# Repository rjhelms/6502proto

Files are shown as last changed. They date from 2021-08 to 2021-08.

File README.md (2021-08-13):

# 6502 Protoboard

A prototyping board for experimenting with 6502 hardware and software design



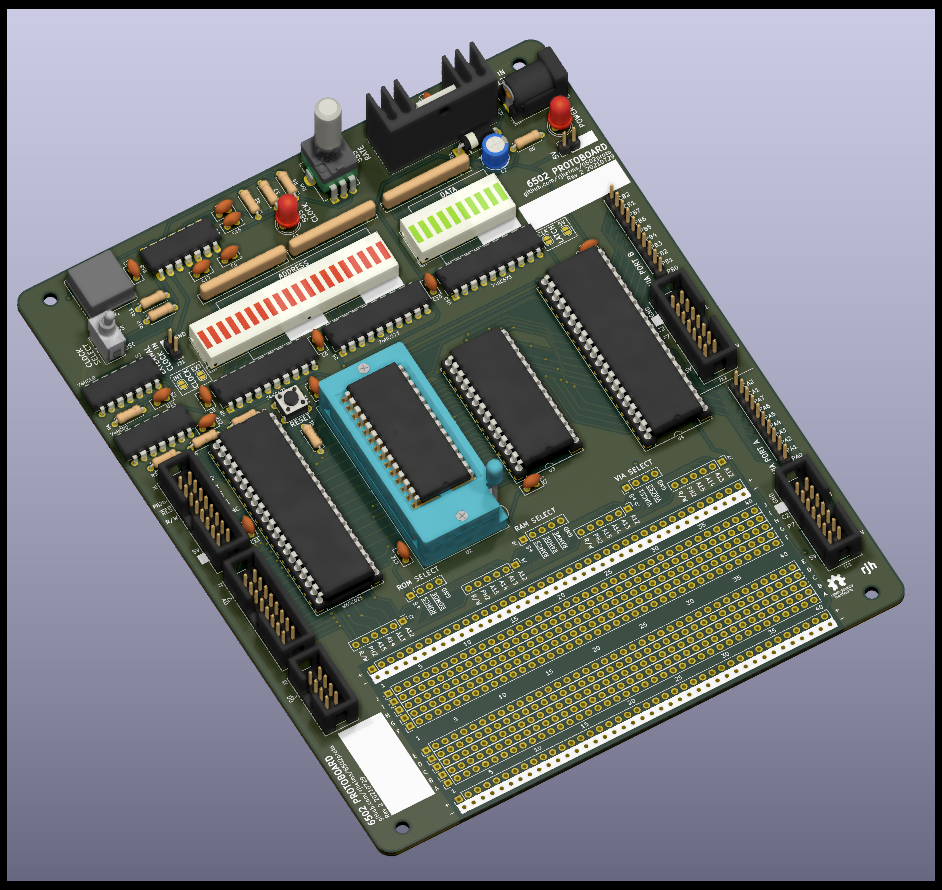
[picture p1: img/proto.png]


This board implements a minimal 6502 system, containing a 65C02 processor, a 65C22 Versatile Interface Adapter (VIA), a 32kB EEPROM and 32kB of SRAM.

This project would not have been possible without Garth Wilson's excellent [6502 Primer](https://wilsonminesco.com/6502primer/index.html), which is eseential reading for anyone looking to get started with 6502 homebrew.

## Table of contents

- [Features](#features)
- [Building](#building)
- [Implementing address decoding](#implementing-address-decoding)
  - [Minimal setup](#minimal-setup)
  - [Adding more I/O](#adding-more-i-o)
- [Header pinouts](#header-pinouts)
  - [CPU signals](#cpu-signals)
  - [Address bus](#address-bus)
  - [CPU bus](#cpu-bus)
  - [VIA ports](#via-ports)
- [Useful links](#useful-links)

## Features

- Two clock sources: 1MHz crystal oscillator "fast" clock and 555-timer based "slow" clock (approx 0.5Hz - 500Hz)
- Blinkenlights for the address and data buses
- Header for external clock source, if desired
- 400-point breadboard area, for address decoding and other small circuits
- IDC headers for address & data buses, CPU signals, and both VIA ports

## Building

More to come - for now, refer to the [interactive BOM](https://rjhelms.github.io/6502proto/ibom.html).

## Implementing address decoding

In order to let the 6502 processor talk to other chips, any 6502 system requires some address decoding logic. The board has no address decoding built in; it is up to the builder to implement their chosen address decoding with the breadboard area.

Pads above the breadboard area provide access to the 4 highest bytes of the address bus, as well as the PH2 clock and R/W, and the relevant inputs for each of the on-board ICs.

The [address decoding chapter](https://wilsonminesco.com/6502primer/addr_decoding.html) of Garth Wilson's primer is well worth a read before deciding what to implement.

Some key considerations when choosing an address decoding scheme:

- Each address should select at most one device
- Writes to RAM should only occur when PH2 is high
- RAM should be at the bottom of the address space, to include the  zero  page ($0000-$00FF) and stack ($0100-$01FF).
- ROM should be at the top of the address space, to include the reset and interrupt vectors at $FFFA-$FFFF.

### Minimal setup

For a system only using the RAM, ROM, and VIA chips on board, satisfactory results can be achieved with a single 74HC00 quad NAND gate:

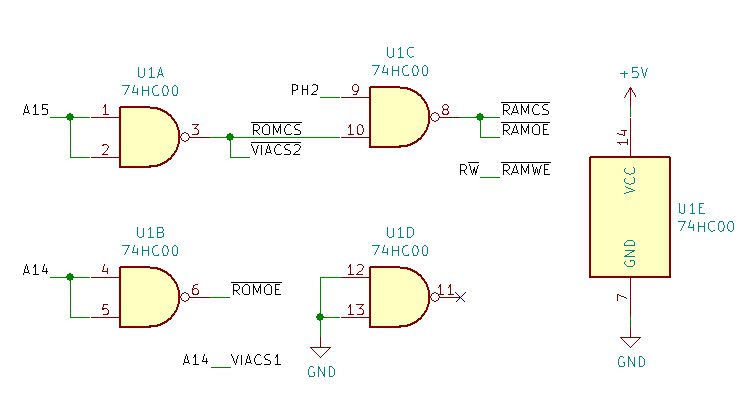
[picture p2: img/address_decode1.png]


| Start | End | Device |
|---|---|---|
| $0000 | $7FFF | RAM |
| $8000 | $BFFF | VIA |
| $C000 | $FFFF | ROM |

With only 64kB of address space and 32kB of both RAM and ROM, at least some portion of one of these will need to be masked by the VIA or other devices. This logic masks the lower half of ROM, resulting in a system with 32kB of RAM and 16kB of ROM.

A similar addressing scheme with 16kB of RAM and 32kB of ROM can also be implemented with one 74HC00.

### Adding more I/O

The minimal setup above works just fine for the chips on the protoboard, but doesn't leave any room for expanding the system any further. Also, while the VIA only needs 16 bytes of address space, the above setup allocates a whole 16kB to it!

By using a 74HC138 line decoder, that 16kB can be split into 8 2kB segments, each addressed by one output.

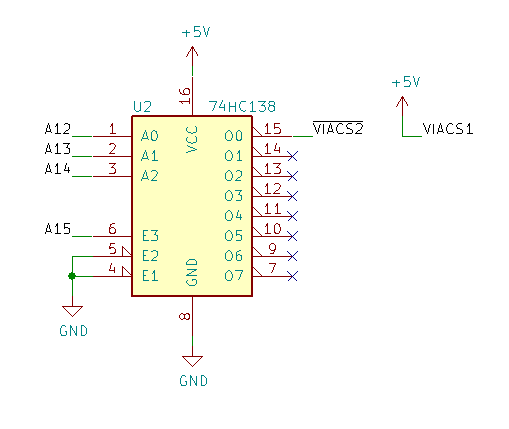
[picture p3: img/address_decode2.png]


| Start | End | Device |
|---|---|---|
| $0000 | $7FFF | RAM |
| $8000 | $87FF | (VIA) '138 output 0 |
...
| $B800 | $BFFF | '138 output 7 |
| $C000 | $FFFF | ROM    |

## Header pinouts

### CPU signals

| Pin | Signal | Pin | Signal |
|-----|---|-----|---|
| 1 | PH2 | 2 | PH2 |
| 3 | RESET  | 4 | RDY |
| 5 | R/W | 6 | IRQ |
| 7 | unused | 8 | NMI |
| 9 | unused | 10  | SYNC |
| 11  | unused | 12  | BE |
| 13  | 5V | 14  | 5V |
| 15  | GND | 16  | GND |

### Address bus

| Pin | Signal | Pin | Signal |
|-----|---|-----|---|
| 1 | A0 | 2 | A1 |
| 3 | A2 | 4 | A3 |
| 5 | A4 | 6 | A5 |
| 7 | A6 | 8 | A7 |
| 9 | A8 | 10  | A9 |
| 11  | A10 | 12  | A11 |
| 13  | A12 | 14  | A13 |
| 15  | A14 | 16  | A15 |

### CPU bus

| Pin | Signal | Pin | Signal |
|-----|---|-----|---|
| 1 | D0 | 2 | D1 |
| 3 | D2 | 4 | D3 |
| 5 | D4 | 6 | D5 |
| 7 | D6 | 8 | D7 |

### VIA ports

| Pin | Signal | Pin | Signal |
|-----|---|-----|---|
| 1 | 5V | 2 | 5V |
| 3 | PA0 | 4 | PA1 |
| 5 | PA2 | 6 | PA3 |
| 7 | PA4 | 8 | PA5 |
| 9 | PA6 | 10  | PA7 |
| 11  | CA1 | 12  | CA2 |
| 13  | GND | 14  | GND |

## Useful links

- [6502.org](http://6502.org/) - a wealth of information on 6502 hardware and software
- Garth Wilson's [6502 Primer](https://wilsonminesco.com/6502primer/index.html)
- Western Design Center, with datasheets and other useful info
  - [W65C02S 8-bit Microprocessor](https://www.westerndesigncenter.com/wdc/w65c02s-chip.php)
  - [W65C22 Versatile Interface Adapter (VIA)](https://www.westerndesigncenter.com/wdc/w65c22-chip.php)
- [cc65](https://cc65.github.io/), a 6502 C compiler and assembler

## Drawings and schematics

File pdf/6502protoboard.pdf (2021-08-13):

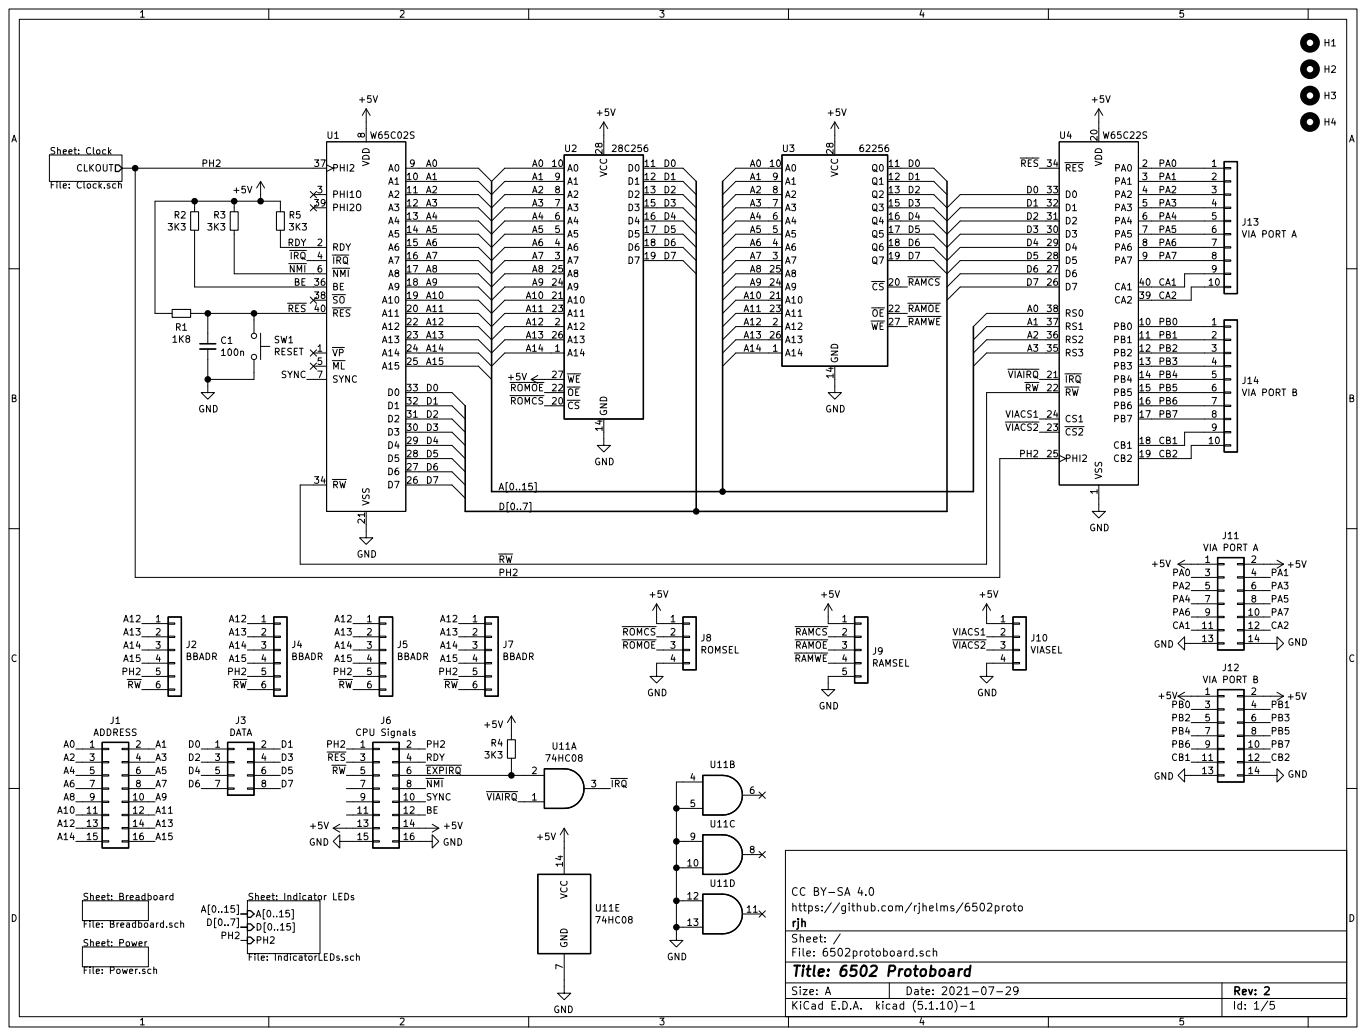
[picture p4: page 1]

Sheet: Clock File: Clock.sch CLKOUT

https://github.com/rjhelms/6502proto CC BY-SA 4.0

File: 6502protoboard.sch Sheet: / rjh

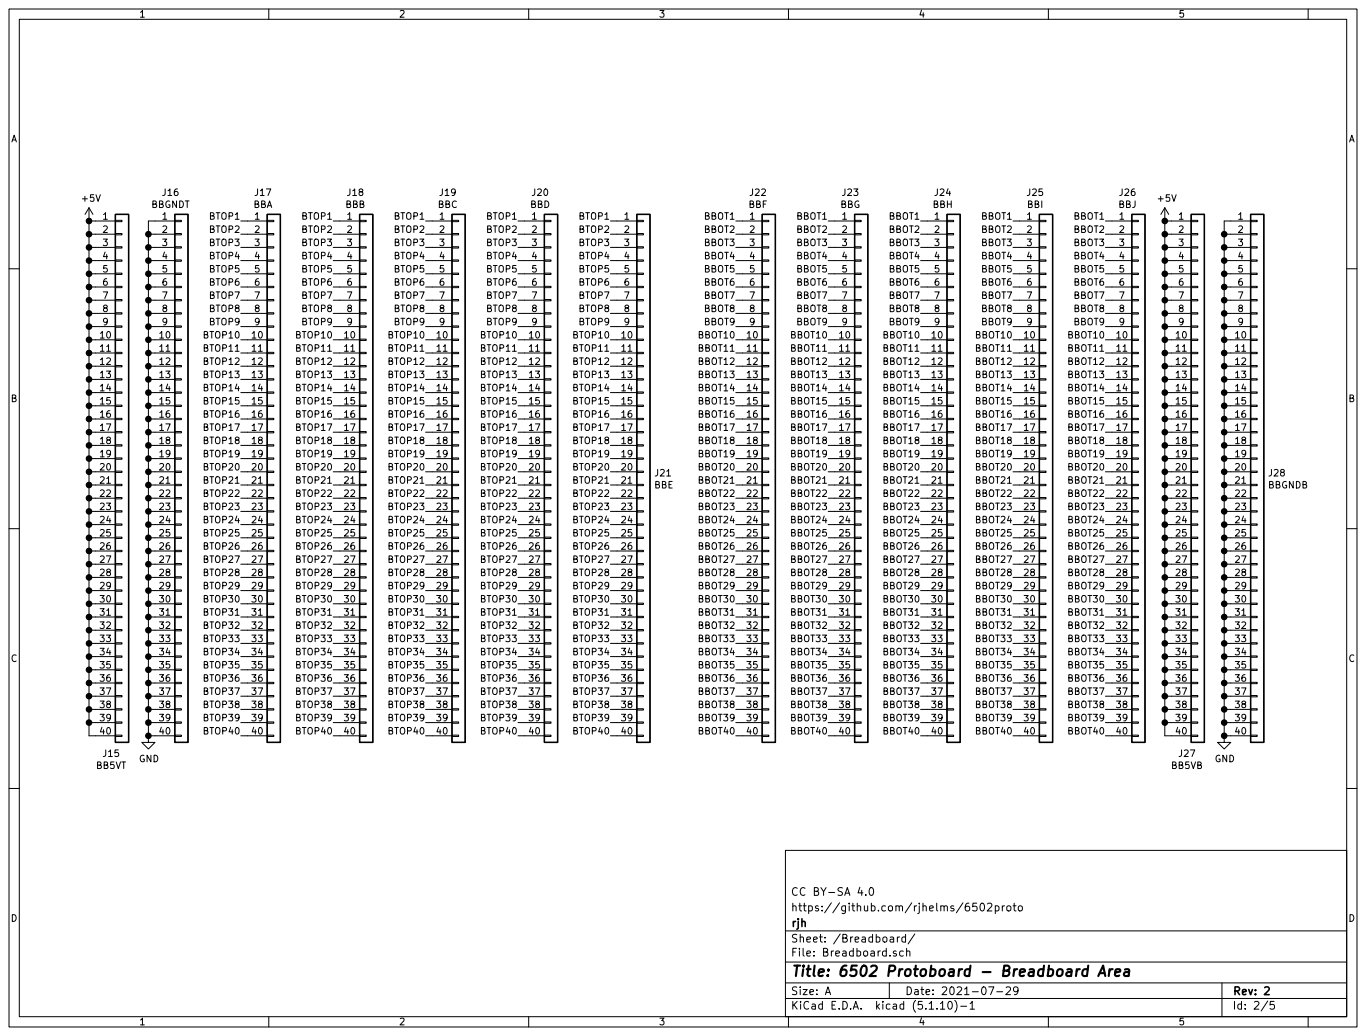
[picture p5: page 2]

https://github.com/rjhelms/6502proto CC BY-SA 4.0

File: Breadboard.sch Sheet: /Breadboard/ rjh

Id: 2/5 Title: 6502 Protoboard - Breadboard Area

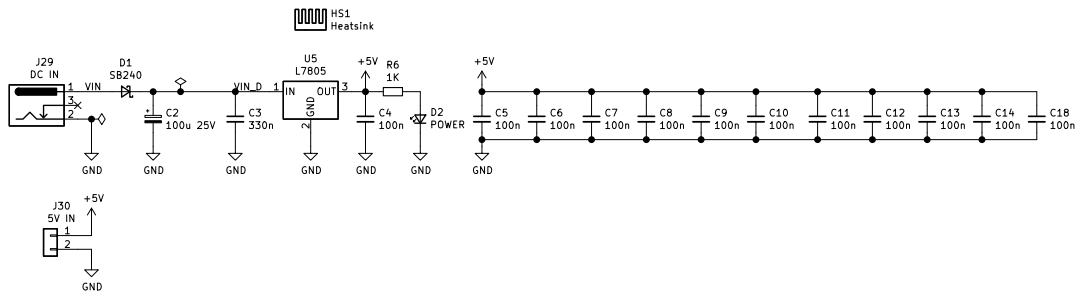
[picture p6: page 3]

https://github.com/rjhelms/6502proto CC BY-SA 4.0 D2 POWER
100n GND

Id: 3/5 Title: 6502 Protoboard - Power File: Power.sch Sheet: /Power/ rjh

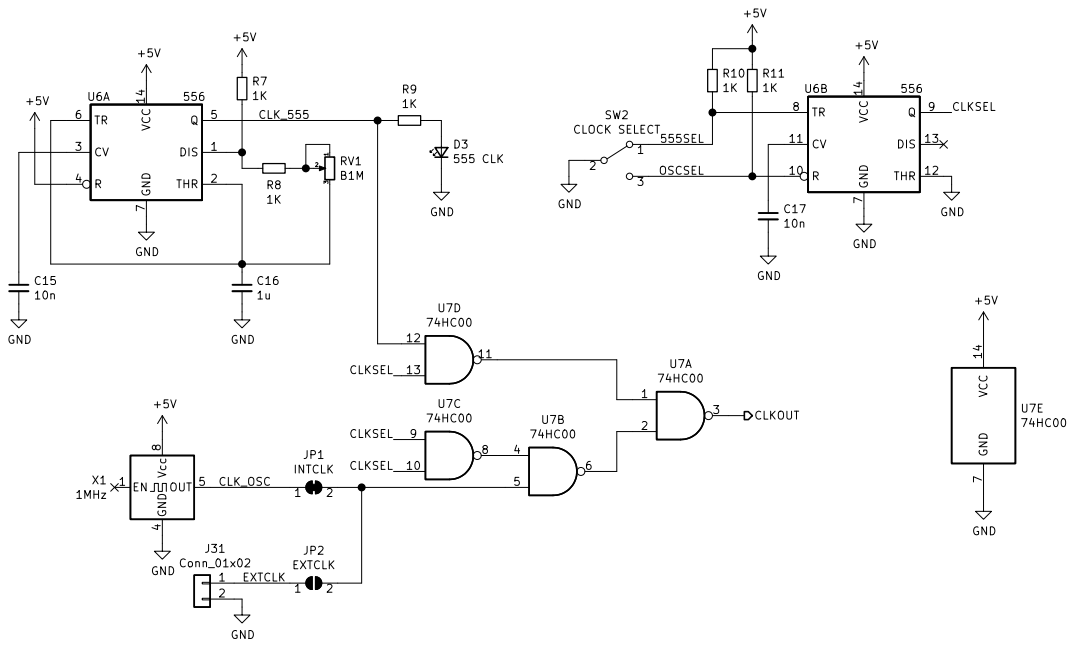
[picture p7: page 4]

https://github.com/rjhelms/6502proto CC BY-SA 4.0

File: Clock.sch Sheet: /Clock/ rjh

Id: 4/5 Title: 6502 Protoboard - Clock

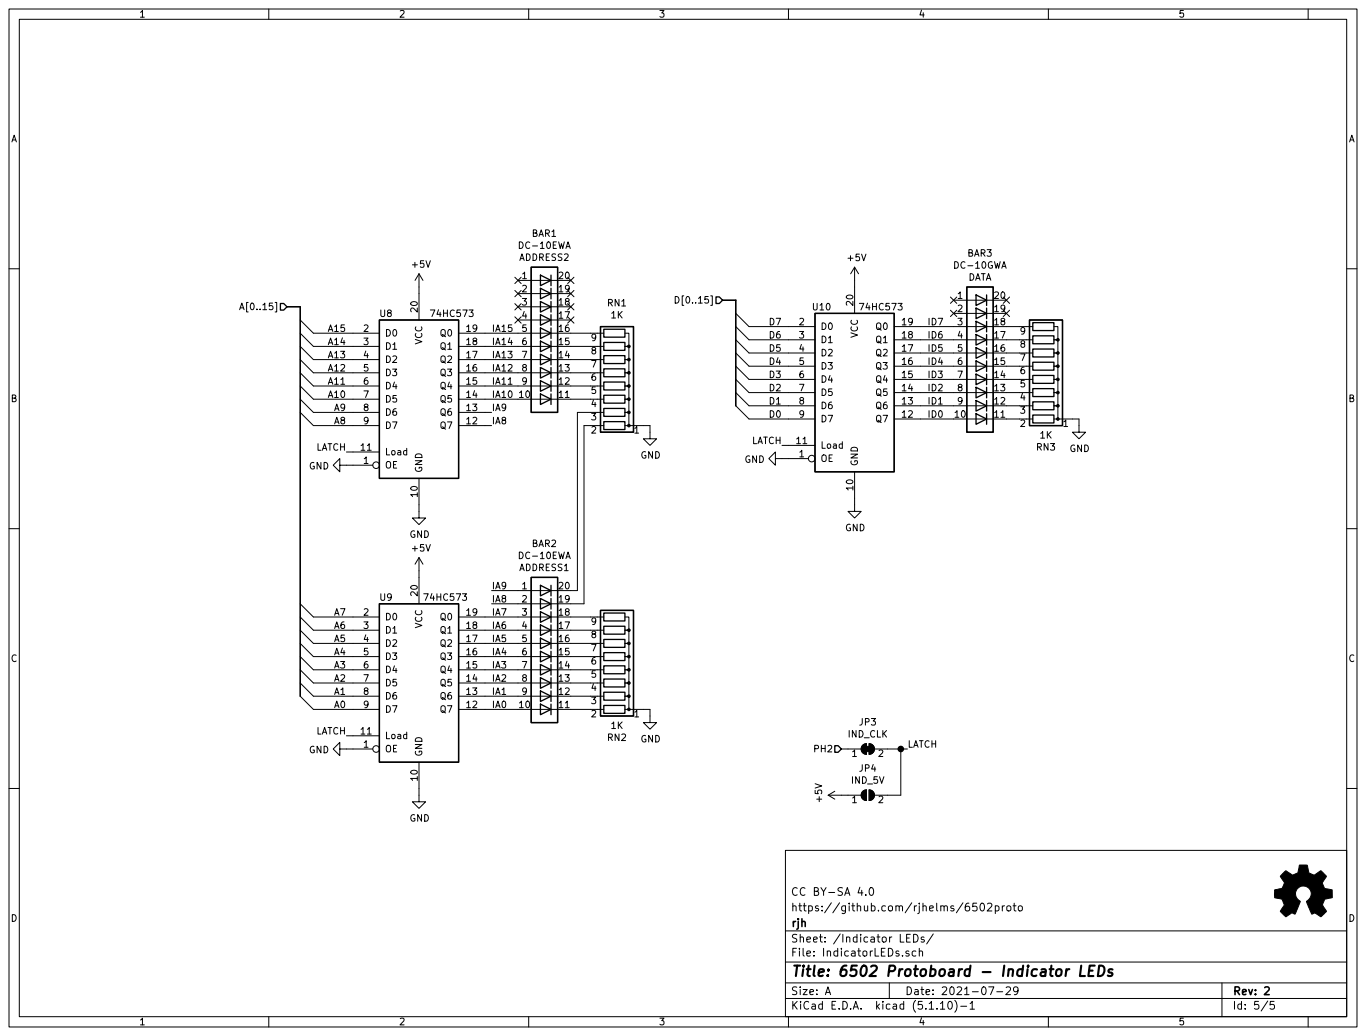
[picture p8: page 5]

File: IndicatorLEDs.sch Sheet: /Indicator LEDs/ rjh

Id: 5/5 Title: 6502 Protoboard - Indicator LEDs

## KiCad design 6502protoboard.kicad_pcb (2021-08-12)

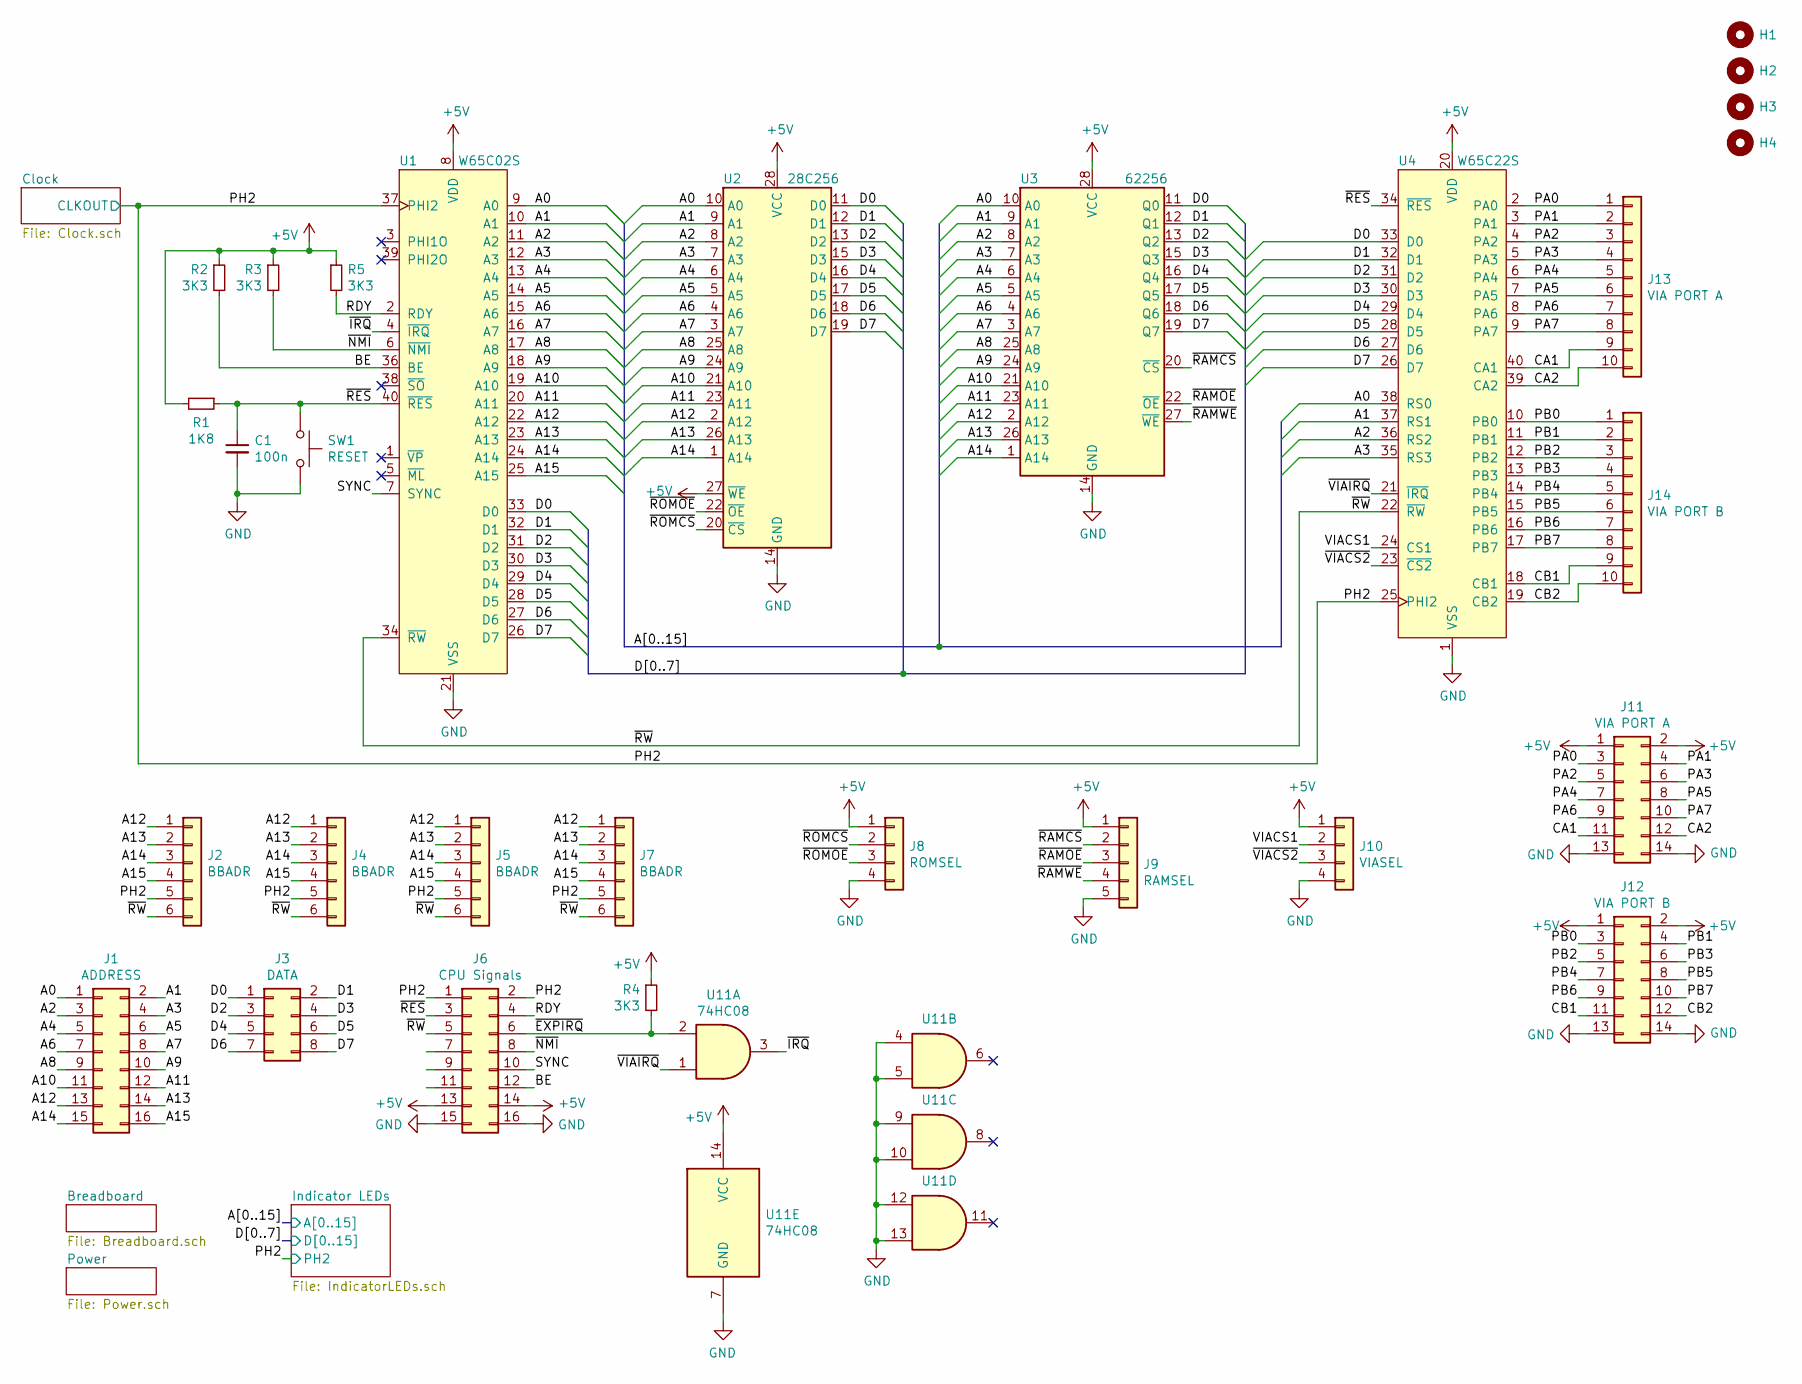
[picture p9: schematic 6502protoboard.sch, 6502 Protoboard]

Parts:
C1: 100n; C_Disc_D5.0mm_W2.5mm_P2.50mm
H1, H2, H3, H4: MountingHole; MountingHole_3.2mm_M3
J1, J6: Conn_02x08_Odd_Even; IDC-Header_2x08_P2.54mm_Vertical
J2, J4, J5, J7: Conn_01x05; PinHeader_1x06_P2.54mm_Vertical
J3: Conn_02x04_Odd_Even; IDC-Header_2x04_P2.54mm_Vertical
J8, J10: Conn_01x04; PinHeader_1x04_P2.54mm_Vertical
J9: Conn_01x05; PinHeader_1x05_P2.54mm_Vertical
J11, J12: Conn_02x07_Odd_Even; IDC-Header_2x07_P2.54mm_Vertical
J13, J14: Conn_01x10; PinHeader_1x10_P2.54mm_Vertical
R1: 1K8; R_Axial_DIN0207_L6.3mm_D2.5mm_P7.62mm_Horizontal
R2, R3, R4, R5: 3K3; R_Axial_DIN0207_L6.3mm_D2.5mm_P7.62mm_Horizontal
SW1: SW_Push; SW_TH_Tactile_Omron_B3F-10xx_Common_Pins
U1: W65C02S; DIP-40_W15.24mm_Socket_LongPads
U2: 28C256; DIP_Socket-28_W11.9_W12.7_W15.24_W17.78_W18.5_3M_228-1277-0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
U3: 62256; DIP-28_W15.24mm_Socket_LongPads
U4: W65C22S; DIP-40_W15.24mm_Socket_LongPads
U11: 74HC08; DIP-14_W7.62mm

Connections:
+5V: J6.13, J6.14, J8.1, J9.1, J10.1, J11.1, J11.2, J12.1, J12.2, R1.2, R2.1, R3.1, R4.1, R5.1, U1.8 (VDD), U2.27 (~WE), U2.28 (VCC), U3.28 (VCC), U4.20 (VDD), U11.14 (VCC); also elsewhere on the board
/A0: J1.1, U1.9 (A0), U2.10 (A0), U3.10 (A0), U4.38 (RS0); also elsewhere on the board
/A1: J1.2, U1.10 (A1), U2.9 (A1), U3.9 (A1), U4.37 (RS1); also elsewhere on the board
/A2: J1.3, U1.11 (A2), U2.8 (A2), U3.8 (A2), U4.36 (RS2); also elsewhere on the board
/A3: J1.4, U1.12 (A3), U2.7 (A3), U3.7 (A3), U4.35 (RS3); also elsewhere on the board
/A4: J1.5, U1.13 (A4), U2.6 (A4), U3.6 (A4); also elsewhere on the board
/A5: J1.6, U1.14 (A5), U2.5 (A5), U3.5 (A5); also elsewhere on the board
/A6: J1.7, U1.15 (A6), U2.4 (A6), U3.4 (A6); also elsewhere on the board
/A7: J1.8, U1.16 (A7), U2.3 (A7), U3.3 (A7); also elsewhere on the board
/A8: J1.9, U1.17 (A8), U2.25 (A8), U3.25 (A8); also elsewhere on the board
/A9: J1.10, U1.18 (A9), U2.24 (A9), U3.24 (A9); also elsewhere on the board
/A10: J1.11, U1.19 (A10), U2.21 (A10), U3.21 (A10); also elsewhere on the board
/A11: J1.12, U1.20 (A11), U2.23 (A11), U3.23 (A11); also elsewhere on the board
/A12: J1.13, J2.1, J4.1, J5.1, J7.1, U1.22 (A12), U2.2 (A12), U3.2 (A12); also elsewhere on the board
/A13: J1.14, J2.2, J4.2, J5.2, J7.2, U1.23 (A13), U2.26 (A13), U3.26 (A13); also elsewhere on the board
/A14: J1.15, J2.3, J4.3, J5.3, J7.3, U1.24 (A14), U2.1 (A14), U3.1 (A14); also elsewhere on the board
/A15: J1.16, J2.4, J4.4, J5.4, J7.4, U1.25 (A15); also elsewhere on the board
/BE: J6.12, R2.2, U1.36 (BE)
/CA1: J11.11, J13.9, U4.40 (CA1)
/CA2: J11.12, J13.10, U4.39 (CA2)
/CB1: J12.11, J14.9, U4.18 (CB1)
/CB2: J12.12, J14.10, U4.19 (CB2)
/D0: J3.1, U1.33 (D0), U2.11 (D0), U3.11 (Q0), U4.33 (D0); also elsewhere on the board
/D1: J3.2, U1.32 (D1), U2.12 (D1), U3.12 (Q1), U4.32 (D1); also elsewhere on the board
/D2: J3.3, U1.31 (D2), U2.13 (D2), U3.13 (Q2), U4.31 (D2); also elsewhere on the board
/D3: J3.4, U1.30 (D3), U2.15 (D3), U3.15 (Q3), U4.30 (D3); also elsewhere on the board
/D4: J3.5, U1.29 (D4), U2.16 (D4), U3.16 (Q4), U4.29 (D4); also elsewhere on the board
/D5: J3.6, U1.28 (D5), U2.17 (D5), U3.17 (Q5), U4.28 (D5); also elsewhere on the board
/D6: J3.7, U1.27 (D6), U2.18 (D6), U3.18 (Q6), U4.27 (D6); also elsewhere on the board
/D7: J3.8, U1.26 (D7), U2.19 (D7), U3.19 (Q7), U4.26 (D7); also elsewhere on the board
/PA0: J11.3, J13.1, U4.2 (PA0)
/PA1: J11.4, J13.2, U4.3 (PA1)
/PA2: J11.5, J13.3, U4.4 (PA2)
/PA3: J11.6, J13.4, U4.5 (PA3)
/PA4: J11.7, J13.5, U4.6 (PA4)
/PA5: J11.8, J13.6, U4.7 (PA5)
/PA6: J11.9, J13.7, U4.8 (PA6)
/PA7: J11.10, J13.8, U4.9 (PA7)
/PB0: J12.3, J14.1, U4.10 (PB0)
/PB1: J12.4, J14.2, U4.11 (PB1)
/PB2: J12.5, J14.3, U4.12 (PB2)
/PB3: J12.6, J14.4, U4.13 (PB3)
/PB4: J12.7, J14.5, U4.14 (PB4)
/PB5: J12.8, J14.6, U4.15 (PB5)
/PB6: J12.9, J14.7, U4.16 (PB6)
/PB7: J12.10, J14.8, U4.17 (PB7)
/PH2: J2.5, J4.5, J5.5, J6.1, J6.2, J7.5, U1.37 (PHI2), U4.25 (PHI2); also elsewhere on the board
/RDY: J6.4, R5.2, U1.2 (RDY)
/SYNC: J6.10, U1.7 (SYNC)
/VIACS1: J10.2, U4.24 (CS1)
/~EXPIRQ: J6.6, R4.2, U11.2
/~IRQ: U1.4 (~IRQ), U11.3
/~NMI: J6.8, R3.2, U1.6 (~NMI)
/~RAMCS: J9.2, U3.20 (~CS)
/~RAMOE: J9.3, U3.22 (~OE)
/~RAMWE: J9.4, U3.27 (~WE)
/~RES: C1.1, J6.3, R1.1, SW1.2, U1.40 (~RES), U4.34 (~RES)
/~ROMCS: J8.2, U2.20 (~CS)
/~ROMOE: J8.3, U2.22 (~OE)
/~RW: J2.6, J4.6, J5.6, J6.5, J7.6, U1.34 (~RW), U4.22 (~RW)
/~VIACS2: J10.3, U4.23 (~CS2)
/~VIAIRQ: U4.21 (~IRQ), U11.1
GND: C1.2, J6.15, J6.16, J8.4, J9.5, J10.4, J11.13, J11.14, J12.13, J12.14, SW1.1, U1.21 (VSS), U2.14 (GND), U3.14 (GND), U4.1 (VSS), U11.4, U11.5, U11.7 (GND), U11.9, U11.10, U11.12, U11.13; also elsewhere on the board

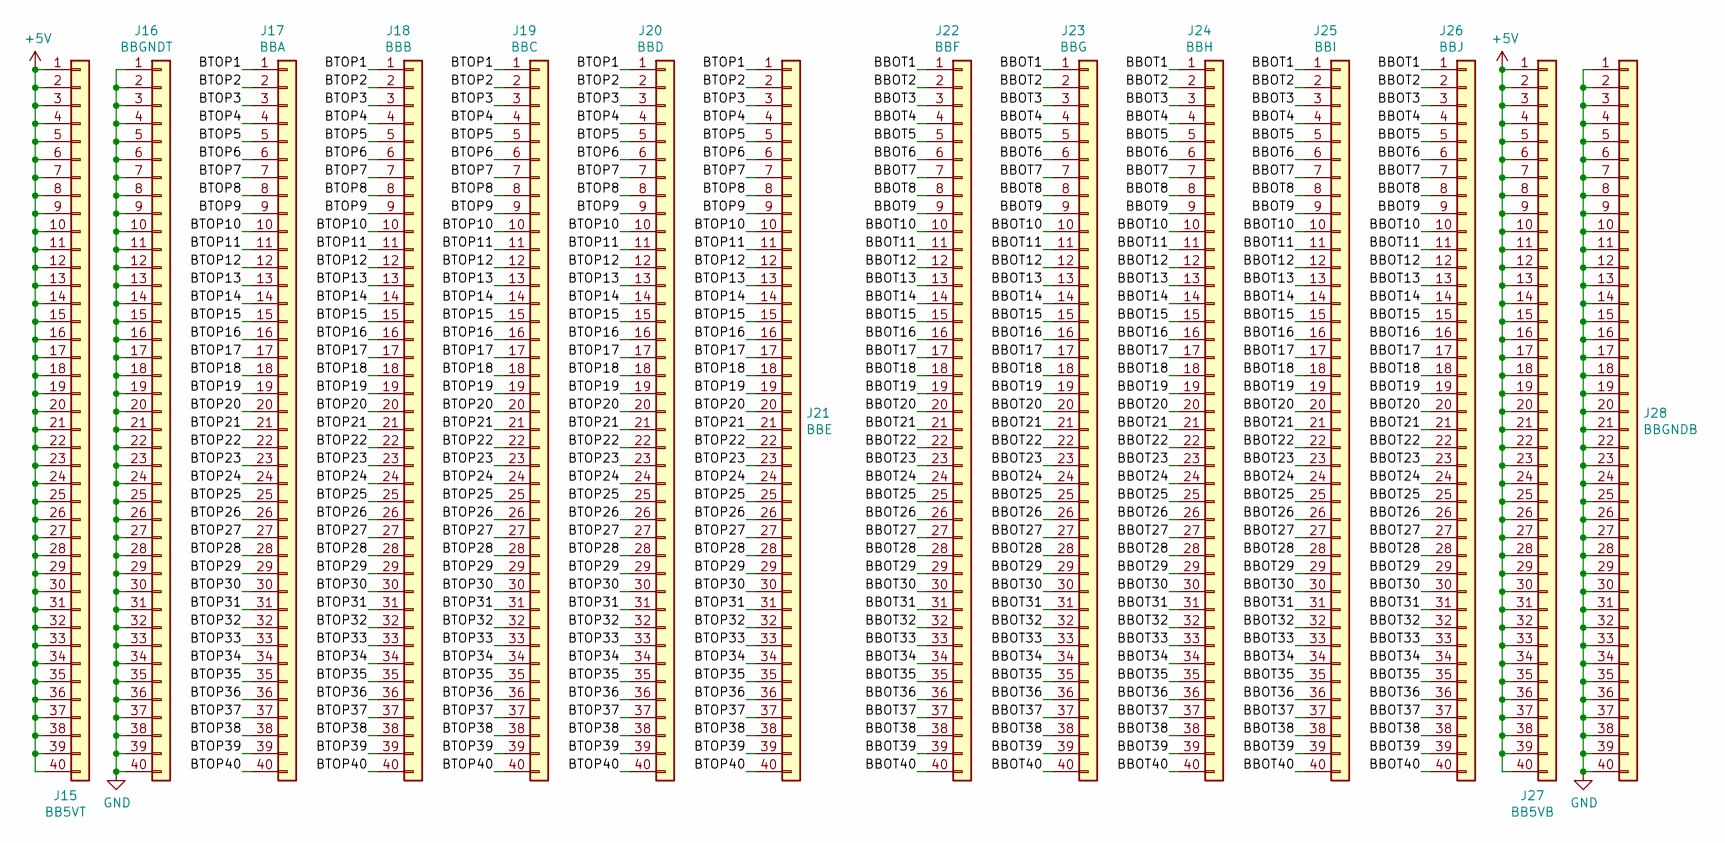
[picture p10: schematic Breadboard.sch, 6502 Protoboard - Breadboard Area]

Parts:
J15, J16, J17, J18, J19, J20, J21, J22, J23, J24, J25, J26, J27, J28: Conn_01x40; PinHeader_1x40_P2.54mm_Vertical

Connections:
+5V: J15.1, J15.2, J15.3, J15.4, J15.5, J15.6, J15.7, J15.8, J15.9, J15.10, J15.11, J15.12, J15.13, J15.14, J15.15, J15.16, J15.17, J15.18, J15.19, J15.20, J15.21, J15.22, J15.23, J15.24, J15.25, J15.26, J15.27, J15.28, J15.29, J15.30, J15.31, J15.32, J15.33, J15.34, J15.35, J15.36, J15.37, J15.38, J15.39, J15.40, J27.1, J27.2, J27.3, J27.4, J27.5, J27.6, J27.7, J27.8, J27.9, J27.10, J27.11, J27.12, J27.13, J27.14, J27.15, J27.16, J27.17, J27.18, J27.19, J27.20, J27.21, J27.22, J27.23, J27.24, J27.25, J27.26, J27.27, J27.28, J27.29, J27.30, J27.31, J27.32, J27.33, J27.34, J27.35, J27.36, J27.37, J27.38, J27.39, J27.40; also elsewhere on the board
/Breadboard/BBOT1: J22.1, J23.1, J24.1, J25.1, J26.1
/Breadboard/BBOT2: J22.2, J23.2, J24.2, J25.2, J26.2
/Breadboard/BBOT3: J22.3, J23.3, J24.3, J25.3, J26.3
/Breadboard/BBOT4: J22.4, J23.4, J24.4, J25.4, J26.4
/Breadboard/BBOT5: J22.5, J23.5, J24.5, J25.5, J26.5
/Breadboard/BBOT6: J22.6, J23.6, J24.6, J25.6, J26.6
/Breadboard/BBOT7: J22.7, J23.7, J24.7, J25.7, J26.7
/Breadboard/BBOT8: J22.8, J23.8, J24.8, J25.8, J26.8
/Breadboard/BBOT9: J22.9, J23.9, J24.9, J25.9, J26.9
/Breadboard/BBOT10: J22.10, J23.10, J24.10, J25.10, J26.10
/Breadboard/BBOT11: J22.11, J23.11, J24.11, J25.11, J26.11
/Breadboard/BBOT12: J22.12, J23.12, J24.12, J25.12, J26.12
/Breadboard/BBOT13: J22.13, J23.13, J24.13, J25.13, J26.13
/Breadboard/BBOT14: J22.14, J23.14, J24.14, J25.14, J26.14
/Breadboard/BBOT15: J22.15, J23.15, J24.15, J25.15, J26.15
/Breadboard/BBOT16: J22.16, J23.16, J24.16, J25.16, J26.16
/Breadboard/BBOT17: J22.17, J23.17, J24.17, J25.17, J26.17
/Breadboard/BBOT18: J22.18, J23.18, J24.18, J25.18, J26.18
/Breadboard/BBOT19: J22.19, J23.19, J24.19, J25.19, J26.19
/Breadboard/BBOT20: J22.20, J23.20, J24.20, J25.20, J26.20
/Breadboard/BBOT21: J22.21, J23.21, J24.21, J25.21, J26.21
/Breadboard/BBOT22: J22.22, J23.22, J24.22, J25.22, J26.22
/Breadboard/BBOT23: J22.23, J23.23, J24.23, J25.23, J26.23
/Breadboard/BBOT24: J22.24, J23.24, J24.24, J25.24, J26.24
/Breadboard/BBOT25: J22.25, J23.25, J24.25, J25.25, J26.25
/Breadboard/BBOT26: J22.26, J23.26, J24.26, J25.26, J26.26
/Breadboard/BBOT27: J22.27, J23.27, J24.27, J25.27, J26.27
/Breadboard/BBOT28: J22.28, J23.28, J24.28, J25.28, J26.28
/Breadboard/BBOT29: J22.29, J23.29, J24.29, J25.29, J26.29
/Breadboard/BBOT30: J22.30, J23.30, J24.30, J25.30, J26.30
/Breadboard/BBOT31: J22.31, J23.31, J24.31, J25.31, J26.31
/Breadboard/BBOT32: J22.32, J23.32, J24.32, J25.32, J26.32
/Breadboard/BBOT33: J22.33, J23.33, J24.33, J25.33, J26.33
/Breadboard/BBOT34: J22.34, J23.34, J24.34, J25.34, J26.34
/Breadboard/BBOT35: J22.35, J23.35, J24.35, J25.35, J26.35
/Breadboard/BBOT36: J22.36, J23.36, J24.36, J25.36, J26.36
/Breadboard/BBOT37: J22.37, J23.37, J24.37, J25.37, J26.37
/Breadboard/BBOT38: J22.38, J23.38, J24.38, J25.38, J26.38
/Breadboard/BBOT39: J22.39, J23.39, J24.39, J25.39, J26.39
/Breadboard/BBOT40: J22.40, J23.40, J24.40, J25.40, J26.40
/Breadboard/BTOP1: J17.1, J18.1, J19.1, J20.1, J21.1
/Breadboard/BTOP2: J17.2, J18.2, J19.2, J20.2, J21.2
/Breadboard/BTOP3: J17.3, J18.3, J19.3, J20.3, J21.3
/Breadboard/BTOP4: J17.4, J18.4, J19.4, J20.4, J21.4
/Breadboard/BTOP5: J17.5, J18.5, J19.5, J20.5, J21.5
/Breadboard/BTOP6: J17.6, J18.6, J19.6, J20.6, J21.6
/Breadboard/BTOP7: J17.7, J18.7, J19.7, J20.7, J21.7
/Breadboard/BTOP8: J17.8, J18.8, J19.8, J20.8, J21.8
/Breadboard/BTOP9: J17.9, J18.9, J19.9, J20.9, J21.9
/Breadboard/BTOP10: J17.10, J18.10, J19.10, J20.10, J21.10
/Breadboard/BTOP11: J17.11, J18.11, J19.11, J20.11, J21.11
/Breadboard/BTOP12: J17.12, J18.12, J19.12, J20.12, J21.12
/Breadboard/BTOP13: J17.13, J18.13, J19.13, J20.13, J21.13
/Breadboard/BTOP14: J17.14, J18.14, J19.14, J20.14, J21.14
/Breadboard/BTOP15: J17.15, J18.15, J19.15, J20.15, J21.15
/Breadboard/BTOP16: J17.16, J18.16, J19.16, J20.16, J21.16
/Breadboard/BTOP17: J17.17, J18.17, J19.17, J20.17, J21.17
/Breadboard/BTOP18: J17.18, J18.18, J19.18, J20.18, J21.18
/Breadboard/BTOP19: J17.19, J18.19, J19.19, J20.19, J21.19
/Breadboard/BTOP20: J17.20, J18.20, J19.20, J20.20, J21.20
/Breadboard/BTOP21: J17.21, J18.21, J19.21, J20.21, J21.21
/Breadboard/BTOP22: J17.22, J18.22, J19.22, J20.22, J21.22
/Breadboard/BTOP23: J17.23, J18.23, J19.23, J20.23, J21.23
/Breadboard/BTOP24: J17.24, J18.24, J19.24, J20.24, J21.24
/Breadboard/BTOP25: J17.25, J18.25, J19.25, J20.25, J21.25
/Breadboard/BTOP26: J17.26, J18.26, J19.26, J20.26, J21.26
/Breadboard/BTOP27: J17.27, J18.27, J19.27, J20.27, J21.27
/Breadboard/BTOP28: J17.28, J18.28, J19.28, J20.28, J21.28
/Breadboard/BTOP29: J17.29, J18.29, J19.29, J20.29, J21.29
/Breadboard/BTOP30: J17.30, J18.30, J19.30, J20.30, J21.30
/Breadboard/BTOP31: J17.31, J18.31, J19.31, J20.31, J21.31
/Breadboard/BTOP32: J17.32, J18.32, J19.32, J20.32, J21.32
/Breadboard/BTOP33: J17.33, J18.33, J19.33, J20.33, J21.33
/Breadboard/BTOP34: J17.34, J18.34, J19.34, J20.34, J21.34
/Breadboard/BTOP35: J17.35, J18.35, J19.35, J20.35, J21.35
/Breadboard/BTOP36: J17.36, J18.36, J19.36, J20.36, J21.36
/Breadboard/BTOP37: J17.37, J18.37, J19.37, J20.37, J21.37
/Breadboard/BTOP38: J17.38, J18.38, J19.38, J20.38, J21.38
/Breadboard/BTOP39: J17.39, J18.39, J19.39, J20.39, J21.39
/Breadboard/BTOP40: J17.40, J18.40, J19.40, J20.40, J21.40
GND: J16.1, J16.2, J16.3, J16.4, J16.5, J16.6, J16.7, J16.8, J16.9, J16.10, J16.11, J16.12, J16.13, J16.14, J16.15, J16.16, J16.17, J16.18, J16.19, J16.20, J16.21, J16.22, J16.23, J16.24, J16.25, J16.26, J16.27, J16.28, J16.29, J16.30, J16.31, J16.32, J16.33, J16.34, J16.35, J16.36, J16.37, J16.38, J16.39, J16.40, J28.1, J28.2, J28.3, J28.4, J28.5, J28.6, J28.7, J28.8, J28.9, J28.10, J28.11, J28.12, J28.13, J28.14, J28.15, J28.16, J28.17, J28.18, J28.19, J28.20, J28.21, J28.22, J28.23, J28.24, J28.25, J28.26, J28.27, J28.28, J28.29, J28.30, J28.31, J28.32, J28.33, J28.34, J28.35, J28.36, J28.37, J28.38, J28.39, J28.40; also elsewhere on the board

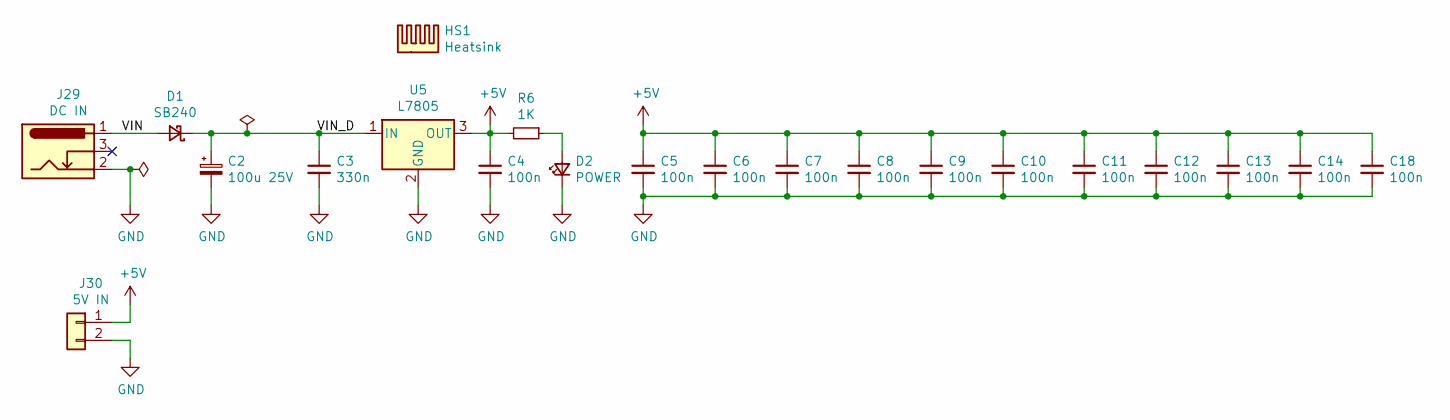
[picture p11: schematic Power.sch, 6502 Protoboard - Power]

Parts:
C2: 100u 25V; CP_Radial_D6.3mm_P2.50mm
C3: 330n; C_Disc_D5.0mm_W2.5mm_P2.50mm
C4, C5, C6, C7, C8, C9, C10, C11, C12, C13, C14, C18: 100n; C_Disc_D5.0mm_W2.5mm_P2.50mm
D1: SB240; D_DO-15_P10.16mm_Horizontal
D2: LED; LED_D5.0mm
HS1: Heatsink; Heatsink_Assman_V4330N
J29: Barrel_Jack_Switch; BarrelJack_Wuerth_6941xx301002
J30: Conn_01x02; PinHeader_1x02_P2.54mm_Vertical
R6: 1K; R_Axial_DIN0207_L6.3mm_D2.5mm_P7.62mm_Horizontal
U5: L7805; TO-220-3_Vertical

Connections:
+5V: C4.1, C5.1, C6.1, C7.1, C8.1, C9.1, C10.1, C11.1, C12.1, C13.1, C14.1, C18.1, J30.1, R6.2, U5.3 (OUT); also elsewhere on the board
/Power/VIN: D1.2 (A), J29.1
/Power/VIN_D: C2.1, C3.1, D1.1 (K), U5.1 (IN)
GND: C2.2, C3.2, C4.2, C5.2, C6.2, C7.2, C8.2, C9.2, C10.2, C11.2, C12.2, C13.2, C14.2, C18.2, D2.1 (K), J29.2, J30.2, U5.2 (GND); also elsewhere on the board
unnamed: D2.2 (A), R6.1

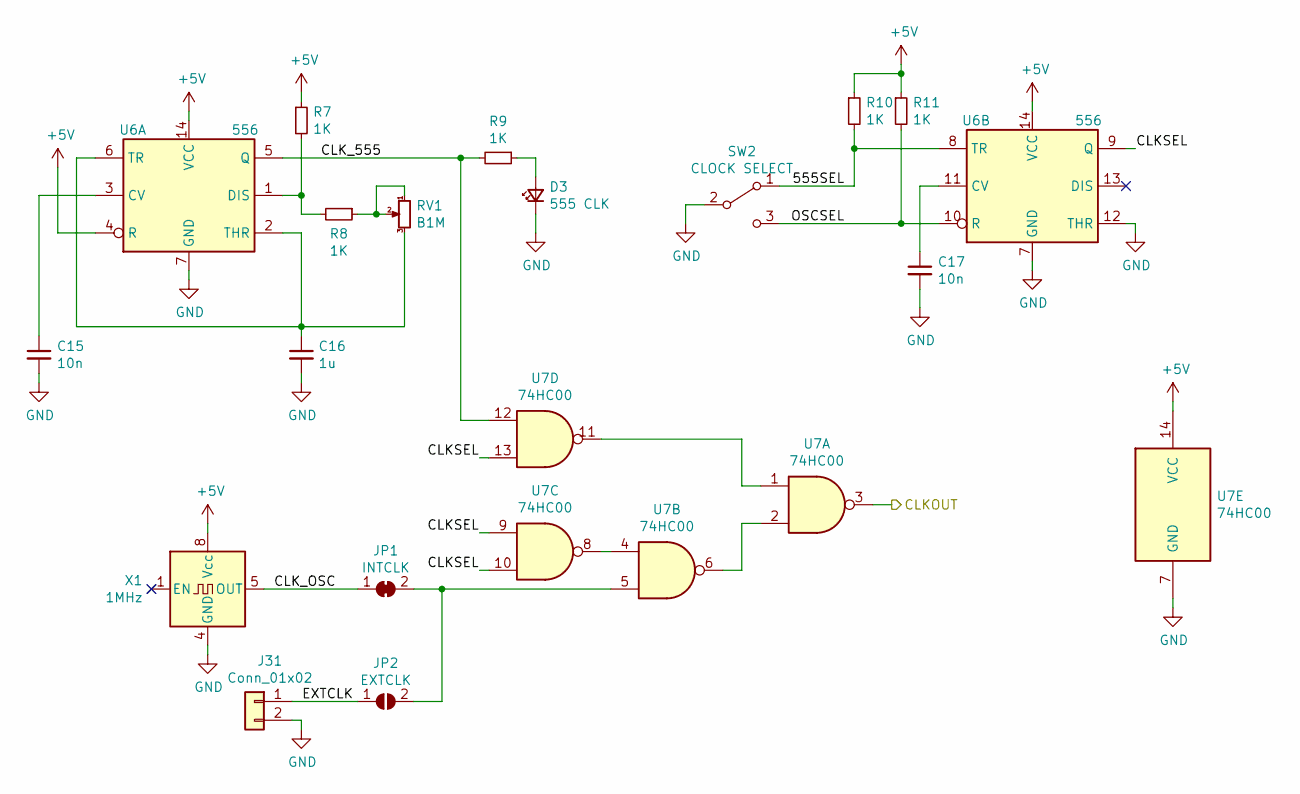
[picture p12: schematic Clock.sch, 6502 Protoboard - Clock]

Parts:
C15, C17: 10n; C_Disc_D5.0mm_W2.5mm_P2.50mm
C16: 1u; C_Disc_D5.0mm_W2.5mm_P2.50mm
D3: LED; LED_D5.0mm
J31: Conn_01x02; PinHeader_1x02_P2.54mm_Vertical
JP1: SolderJumper_2_Open; SolderJumper-2_P1.3mm_Bridged_RoundedPad1.0x1.5mm
JP2: SolderJumper_2_Bridged; SolderJumper-2_P1.3mm_Open_RoundedPad1.0x1.5mm
R7, R8, R9, R10, R11: 1K; R_Axial_DIN0207_L6.3mm_D2.5mm_P7.62mm_Horizontal
RV1: B1M; Potentiometer_Alpha_RD901F-40-00D_Single_Vertical_Centered
SW2: SW_SPDT; SW_SPDT_E-Switch_200MSP1xM2
U6: 556; DIP-14_W7.62mm_LongPads
U7: 74HC00; DIP-14_W7.62mm
X1: 1MHz; Oscillator_DIP-8

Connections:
+5V: R7.1, R10.1, R11.1, U6.4 (R), U6.14 (VCC), U7.14 (VCC), X1.8 (Vcc); also elsewhere on the board
/Clock/555SEL: R10.2, SW2.1 (A), U6.8 (TR)
/Clock/CLKSEL: U6.9 (Q), U7.9, U7.10, U7.13
/Clock/CLK_555: R9.2, U6.5 (Q), U7.12
/Clock/CLK_OSC: JP1.1 (A), X1.5 (OUT)
/Clock/EXTCLK: J31.1, JP2.1 (A)
/Clock/OSCSEL: R11.2, SW2.3 (C), U6.10 (R)
/PH2: U7.3; also elsewhere on the board
GND: C15.2, C16.2, C17.2, D3.1 (K), J31.2, SW2.2 (B), U6.7 (GND), U6.12 (THR), U7.7 (GND), X1.4 (GND); also elsewhere on the board
unnamed: C15.1, U6.3 (CV)
unnamed: C16.1, RV1.3, U6.2 (THR), U6.6 (TR)
unnamed: C17.1, U6.11 (CV)
unnamed: D3.2 (A), R9.1
unnamed: JP1.2 (B), JP2.2 (B), U7.5
unnamed: R7.2, R8.2, U6.1 (DIS)
unnamed: R8.1, RV1.1, RV1.2
unnamed: U7.1, U7.11
unnamed: U7.2, U7.6
unnamed: U7.4, U7.8

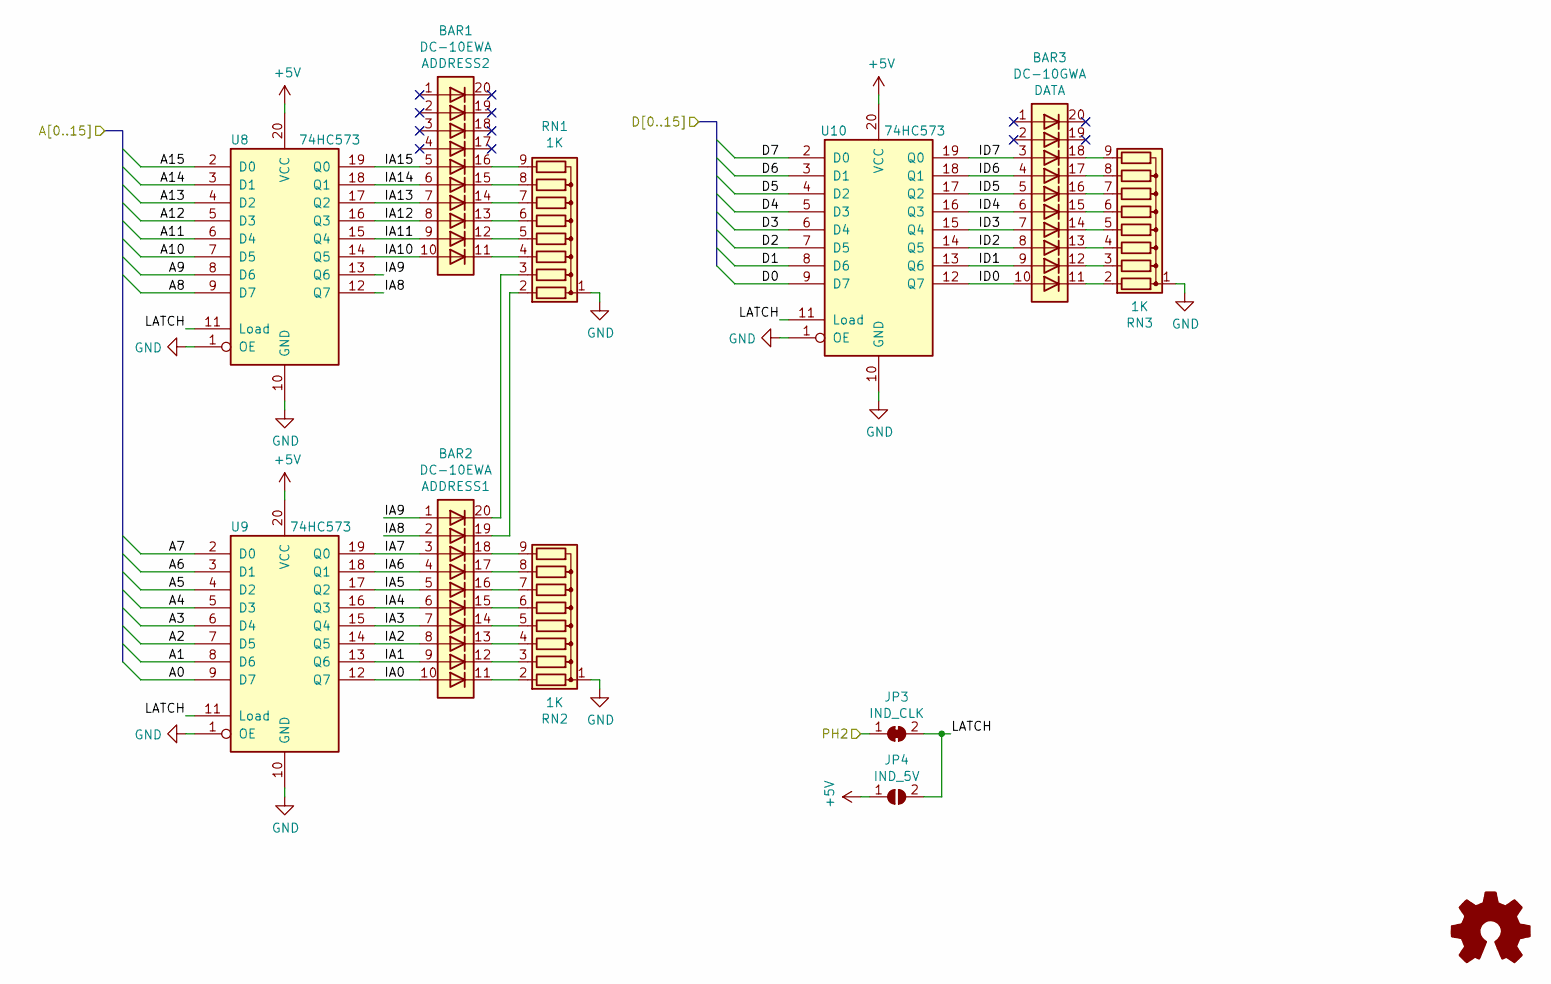
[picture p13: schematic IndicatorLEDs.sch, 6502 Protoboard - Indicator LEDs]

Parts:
BAR1, BAR2: DC-10EWA; HDSP-4830
BAR3: DC-10GWA; HDSP-4850
JP3: SolderJumper_Bridged; SolderJumper-2_P1.3mm_Bridged_RoundedPad1.0x1.5mm
JP4: SolderJumper_Open; SolderJumper-2_P1.3mm_Open_RoundedPad1.0x1.5mm
LOGO1: Logo_Open_Hardware_Small; OSHW-Logo_5.7x6mm_SilkScreen
RN1, RN2, RN3: 1K; R_Array_SIP9
U8, U9, U10: 74HC573; DIP-20_W7.62mm

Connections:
+5V: JP4.1 (A), U8.20 (VCC), U9.20 (VCC), U10.20 (VCC); also elsewhere on the board
/A0: U9.9 (D7); also elsewhere on the board
/A1: U9.8 (D6); also elsewhere on the board
/A2: U9.7 (D5); also elsewhere on the board
/A3: U9.6 (D4); also elsewhere on the board
/A4: U9.5 (D3); also elsewhere on the board
/A5: U9.4 (D2); also elsewhere on the board
/A6: U9.3 (D1); also elsewhere on the board
/A7: U9.2 (D0); also elsewhere on the board
/A8: U8.9 (D7); also elsewhere on the board
/A9: U8.8 (D6); also elsewhere on the board
/A10: U8.7 (D5); also elsewhere on the board
/A11: U8.6 (D4); also elsewhere on the board
/A12: U8.5 (D3); also elsewhere on the board
/A13: U8.4 (D2); also elsewhere on the board
/A14: U8.3 (D1); also elsewhere on the board
/A15: U8.2 (D0); also elsewhere on the board
/D0: U10.9 (D7); also elsewhere on the board
/D1: U10.8 (D6); also elsewhere on the board
/D2: U10.7 (D5); also elsewhere on the board
/D3: U10.6 (D4); also elsewhere on the board
/D4: U10.5 (D3); also elsewhere on the board
/D5: U10.4 (D2); also elsewhere on the board
/D6: U10.3 (D1); also elsewhere on the board
/D7: U10.2 (D0); also elsewhere on the board
/Indicator LEDs/IA0: BAR2.10 (A), U9.12 (Q7)
/Indicator LEDs/IA1: BAR2.9 (A), U9.13 (Q6)
/Indicator LEDs/IA2: BAR2.8 (A), U9.14 (Q5)
/Indicator LEDs/IA3: BAR2.7 (A), U9.15 (Q4)
/Indicator LEDs/IA4: BAR2.6 (A), U9.16 (Q3)
/Indicator LEDs/IA5: BAR2.5 (A), U9.17 (Q2)
/Indicator LEDs/IA6: BAR2.4 (A), U9.18 (Q1)
/Indicator LEDs/IA7: BAR2.3 (A), U9.19 (Q0)
/Indicator LEDs/IA8: BAR2.2 (A), U8.12 (Q7)
/Indicator LEDs/IA9: BAR2.1 (A), U8.13 (Q6)
/Indicator LEDs/IA10: BAR1.10 (A), U8.14 (Q5)
/Indicator LEDs/IA11: BAR1.9 (A), U8.15 (Q4)
/Indicator LEDs/IA12: BAR1.8 (A), U8.16 (Q3)
/Indicator LEDs/IA13: BAR1.7 (A), U8.17 (Q2)
/Indicator LEDs/IA14: BAR1.6 (A), U8.18 (Q1)
/Indicator LEDs/IA15: BAR1.5 (A), U8.19 (Q0)
/Indicator LEDs/ID0: BAR3.10 (A), U10.12 (Q7)
/Indicator LEDs/ID1: BAR3.9 (A), U10.13 (Q6)
/Indicator LEDs/ID2: BAR3.8 (A), U10.14 (Q5)
/Indicator LEDs/ID3: BAR3.7 (A), U10.15 (Q4)
/Indicator LEDs/ID4: BAR3.6 (A), U10.16 (Q3)
/Indicator LEDs/ID5: BAR3.5 (A), U10.17 (Q2)
/Indicator LEDs/ID6: BAR3.4 (A), U10.18 (Q1)
/Indicator LEDs/ID7: BAR3.3 (A), U10.19 (Q0)
/Indicator LEDs/LATCH: JP3.2 (B), JP4.2 (B), U8.11 (Load), U9.11 (Load), U10.11 (Load)
/PH2: JP3.1 (A); also elsewhere on the board
GND: RN1.1 (common), RN2.1 (common), RN3.1 (common), U8.1 (OE), U8.10 (GND), U9.1 (OE), U9.10 (GND), U10.1 (OE), U10.10 (GND); also elsewhere on the board
unnamed: BAR1.11 (K), RN1.4 (R3)
unnamed: BAR1.12 (K), RN1.5 (R4)
unnamed: BAR1.13 (K), RN1.6 (R5)
unnamed: BAR1.14 (K), RN1.7 (R6)
unnamed: BAR1.15 (K), RN1.8 (R7)
unnamed: BAR1.16 (K), RN1.9 (R8)
unnamed: BAR2.11 (K), RN2.2 (R1)
unnamed: BAR2.12 (K), RN2.3 (R2)
unnamed: BAR2.13 (K), RN2.4 (R3)
unnamed: BAR2.14 (K), RN2.5 (R4)
unnamed: BAR2.15 (K), RN2.6 (R5)
unnamed: BAR2.16 (K), RN2.7 (R6)
unnamed: BAR2.17 (K), RN2.8 (R7)
unnamed: BAR2.18 (K), RN2.9 (R8)
unnamed: BAR2.19 (K), RN1.2 (R1)
unnamed: BAR2.20 (K), RN1.3 (R2)
unnamed: BAR3.11 (K), RN3.2 (R1)
unnamed: BAR3.12 (K), RN3.3 (R2)
unnamed: BAR3.13 (K), RN3.4 (R3)
unnamed: BAR3.14 (K), RN3.5 (R4)
unnamed: BAR3.15 (K), RN3.6 (R5)
unnamed: BAR3.16 (K), RN3.7 (R6)
unnamed: BAR3.17 (K), RN3.8 (R7)
unnamed: BAR3.18 (K), RN3.9 (R8)

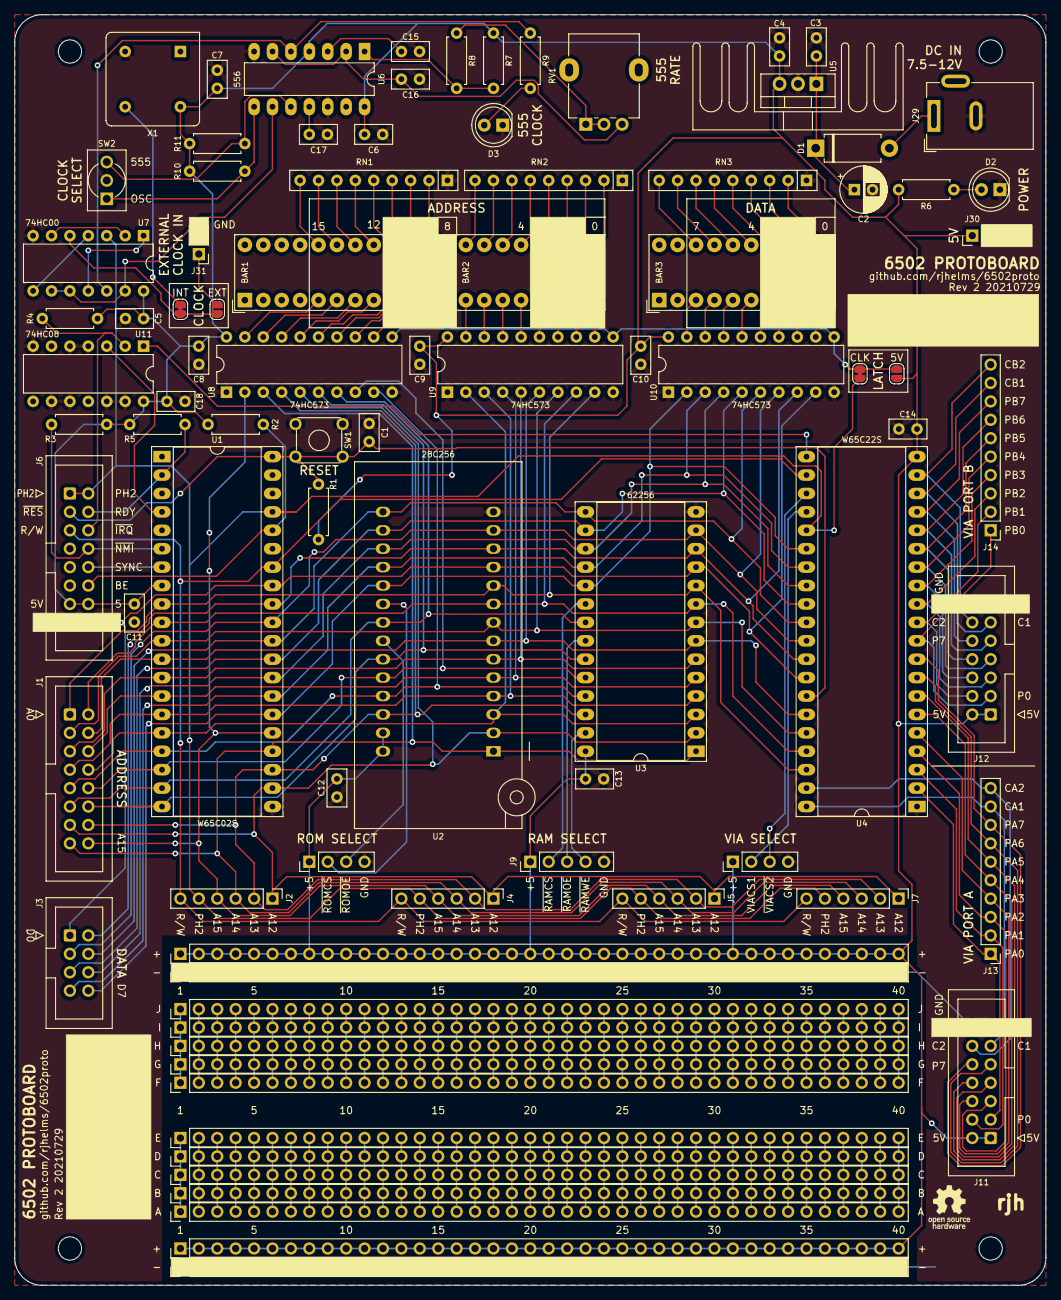
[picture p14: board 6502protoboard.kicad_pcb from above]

Board: 2 copper layers, 142.2 x 175.3 mm, 95 parts (1 on the bottom side), 211 nets.

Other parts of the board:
LOGO1#2: Logo_Open_Hardware_Small; OSHW-Logo_5.7x6mm_SilkScreen

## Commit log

2021-08-12 Commit kicad project at Rev2
    [6502protoboard.kicad_pcb, 6502protoboard.sch, Breadboard.sch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]
2021-08-12 Add github URL to kicad project
    [6502protoboard.kicad_pcb, 6502protoboard.sch, Breadboard.sch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]
2021-08-12 Add license
    [6502protoboard.kicad_pcb, 6502protoboard.sch, Breadboard.sch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]
2021-08-13 Fix power schematic page size
    [Power.sch]
2021-08-13 Add PDF schematic

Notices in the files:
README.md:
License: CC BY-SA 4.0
